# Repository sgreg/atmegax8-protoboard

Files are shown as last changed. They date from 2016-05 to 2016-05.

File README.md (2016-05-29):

# ATmega8X Protoboard
### No fuzz ISP connector board for ATmega48/88/168/328 DIP28

One of those nights where I started something fresh with an ATmega controller and had to detach my breadboard ISP connector adapter from another ongoig project, and I started to wish I wouldn't have to. Breadboards are messy enough without trying to fiddle out single wires. Plus it's some poorly soldered DIY adapter that might just lose a wire any day.

Some time later that night the ATmega8X Protoboard was designed and sent to OSH Park.

Really, nothing fancy, just a little PCB with place for a DIP28 ATmega, an ISP connector and a decoupling capacitor with connectors for a breadboard, i.e. the most basic components for *any* project.

The ISP connector is meant for ATmega48/88/168/328 series microcontrollers, I actually have not checked if others use the same pinout for ISP. If so, it's gonna work with those as well. **Use at your own risk.**

Repository contains KiCad schematics, PCB layout and Gerber files.
Once I received the PCBs and verified they work and fit to the breadboard, it'll be shared on OSH Park.

## Revision B

Resized PCB and added a jumper to optionally route AVCC to VCC.

It was nice to have each pin number added to the PCB in revision A, but the PCB ended up simply too large this way. Placed on a bradboard, it occupied three rows on each side, leaving onl two rows left for wires for each pin. To make matters worse, the additional PCB margin made only one single row really usable.

Revision B squeezes it all more tight together and minimizes the PCB margin. The silk screen pin numbering had to be removed for this though.

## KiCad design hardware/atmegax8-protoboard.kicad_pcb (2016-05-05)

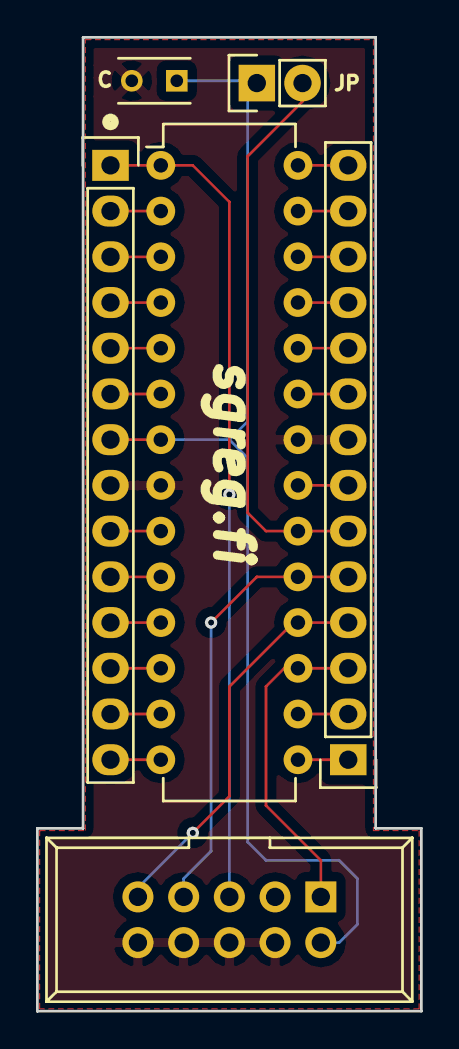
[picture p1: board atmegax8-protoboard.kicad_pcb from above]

Board: 2 copper layers, 21.3 x 54.1 mm, 6 parts (0 on the bottom side), 27 nets.

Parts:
C1: 100n; C_Rect_L4_W2.5_P2.5
IC1: ATMEGA328-P; DIP-28_W7.62mm
JP1: JUMPER; Socket_Strip_Straight_1x02
P1: CONN1; Socket_Strip_Straight_1x14
P2: CONN2; Socket_Strip_Straight_1x14
P3: SERPROG; IDC_Header_Straight_10pins

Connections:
/AREF: IC1.21, P2.7
/AVCC: IC1.20, JP1.2, P2.6
/GND: C1.2, IC1.8, IC1.22, P1.8, P2.8, P3.4, P3.6, P3.8, P3.10
/PB0: IC1.14, P1.14
/PB1: IC1.15, P2.1
/PB2: IC1.16, P2.2
/PB3: IC1.17, P2.3, P3.1
/PB4: IC1.18, P2.4, P3.9
/PB5: IC1.19, P2.5, P3.7
/PB6: IC1.9, P1.9
/PB7: IC1.10, P1.10
/PC0: IC1.23, P2.9
/PC1: IC1.24, P2.10
/PC2: IC1.25, P2.11
/PC3: IC1.26, P2.12
/PC4: IC1.27, P2.13
/PC5: IC1.28, P2.14
/PD0: IC1.2, P1.2
/PD1: IC1.3, P1.3
/PD2: IC1.4, P1.4
/PD3: IC1.5, P1.5
/PD4: IC1.6, P1.6
/PD5: IC1.11, P1.11
/PD6: IC1.12, P1.12
/PD7: IC1.13, P1.13
/RESET: IC1.1, P1.1, P3.5
/VCC: C1.1, IC1.7, JP1.1, P1.7, P3.2

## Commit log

2016-03-08 Revision A schematic and PCB layout
    [atmegax8-protoboard-B.Cu.gbl, atmegax8-protoboard-B.Mask.gbs, atmegax8-protoboard-B.SilkS.gbo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]
2016-03-08 Added _autosave*kicad_pcb to gitignore
2016-05-05 Rev. B schematic, added jumper to route AVCC to VCC
    [atmegax8-protoboard.sch]
2016-05-05 Rev B. PCB, minimized size, re-routed and added jumper
    [atmegax8-protoboard.kicad_pcb]
2016-05-05 Rev. B Gerber files
    [atmegax8-protoboard-B.Cu.gbl, atmegax8-protoboard-B.Mask.gbs, atmegax8-protoboard-B.SilkS.gbo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]
2016-05-05 Fixed AVCC track separating GND fill zone
    [atmegax8-protoboard-B.Cu.gbl, atmegax8-protoboard-B.Mask.gbs, atmegax8-protoboard-B.SilkS.gbo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]

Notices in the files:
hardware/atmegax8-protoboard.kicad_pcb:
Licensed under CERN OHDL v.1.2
